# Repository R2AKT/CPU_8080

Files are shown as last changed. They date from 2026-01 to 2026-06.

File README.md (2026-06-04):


License addendum - https://github.com/R2AKT/CPU_8080/blob/main/Addendum.txt
# CPU_8080
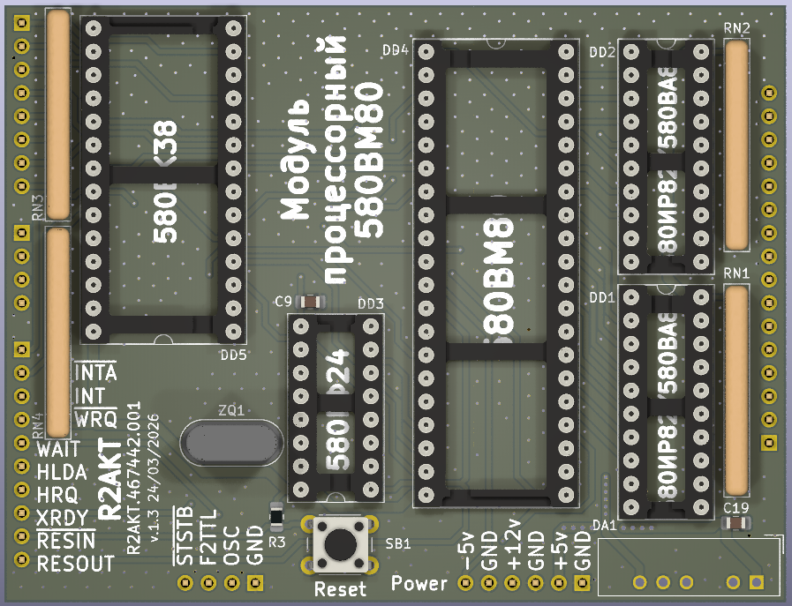
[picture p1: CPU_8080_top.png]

580VM80a (8080a) CPU board.
For Mega-80 (Mega-580) DIY 8-bit micro-computer - https://github.com/R2AKT/Mega-80.

The board includes:
- processor = 580BM80a (8080a);
- clock generator = 580GF24 (8224); 
- data and control bus controller = 580BK28/38 (8228/8238);
- address bus buffer's = 2x580VA86 = (8286).

* There is a project option with the replacement of 580IR82/580V86 with 555AP6 (74LS245).

The board does not contain memory!

Status: tested in conjunction with an 8k linear memory module at a frequency of up to 3 MHz (quartz resonator 27 MHz).

Процессорная плата 580ВМ80а.
Для самодельной 8-битной микро-ЭВМ - https://github.com/R2AKT/Mega-80.

Плата содержит:
- процессор = 580ВМ80а;
- тактовый генератор = 580ГФ24;
- контроллер шины данных и управления = 580ВК28/38;
- буфер шины адреса = 2x580ВА86.

* Имеется вариант проекта с заменой 580ИР82/580ВА86 на 555АП6.

Плата не содержит память!

Статус: проверено совместно с модулем линейной памяти 8к на частоте до 3 МГц (кварцевый резонатор 27 МГц).

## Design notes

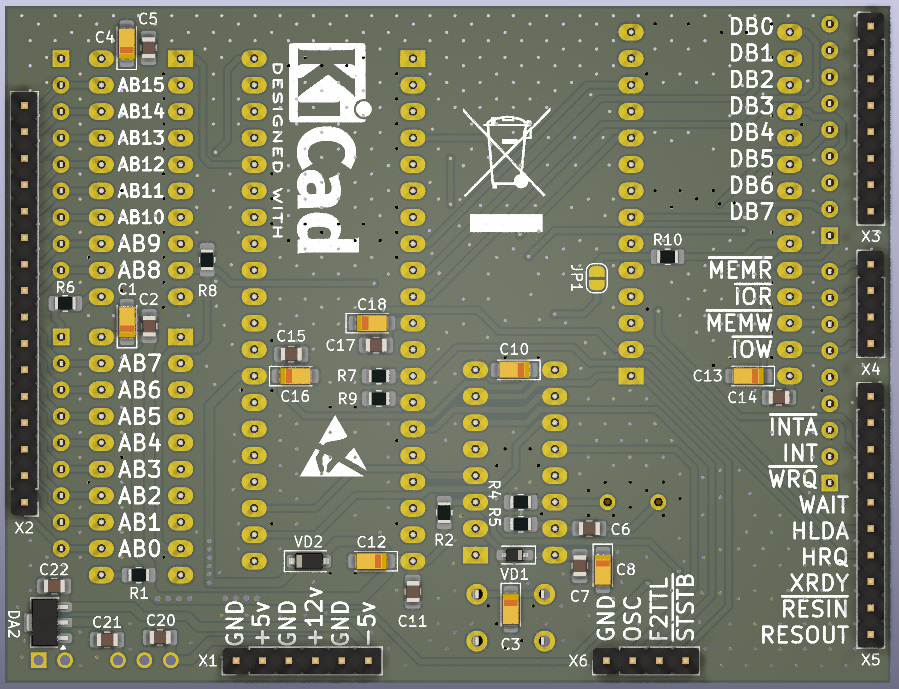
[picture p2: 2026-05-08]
CPU_8080_btn.png

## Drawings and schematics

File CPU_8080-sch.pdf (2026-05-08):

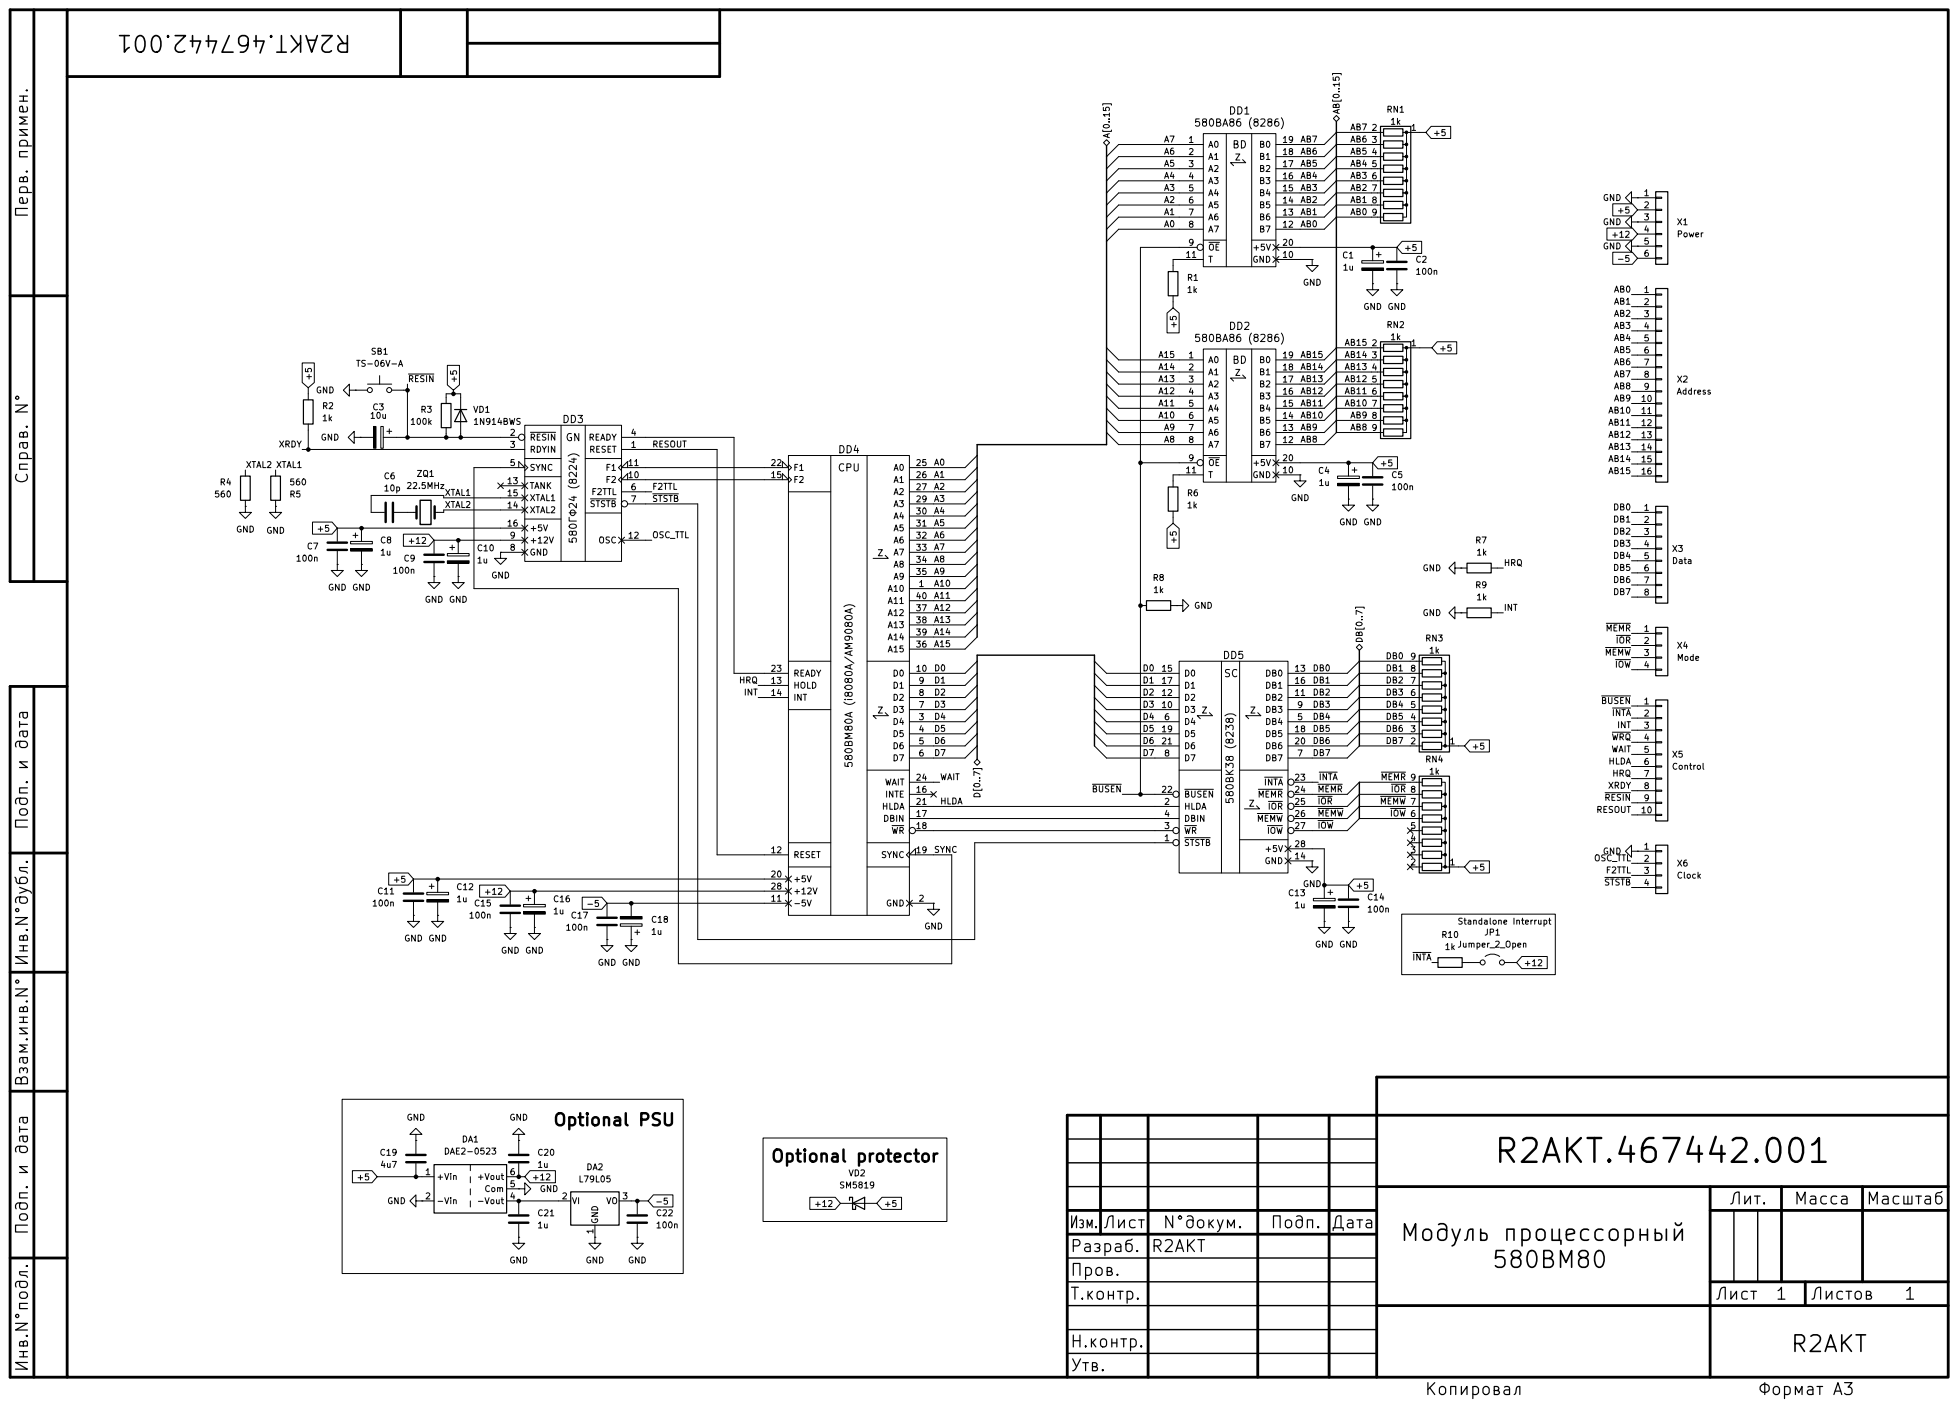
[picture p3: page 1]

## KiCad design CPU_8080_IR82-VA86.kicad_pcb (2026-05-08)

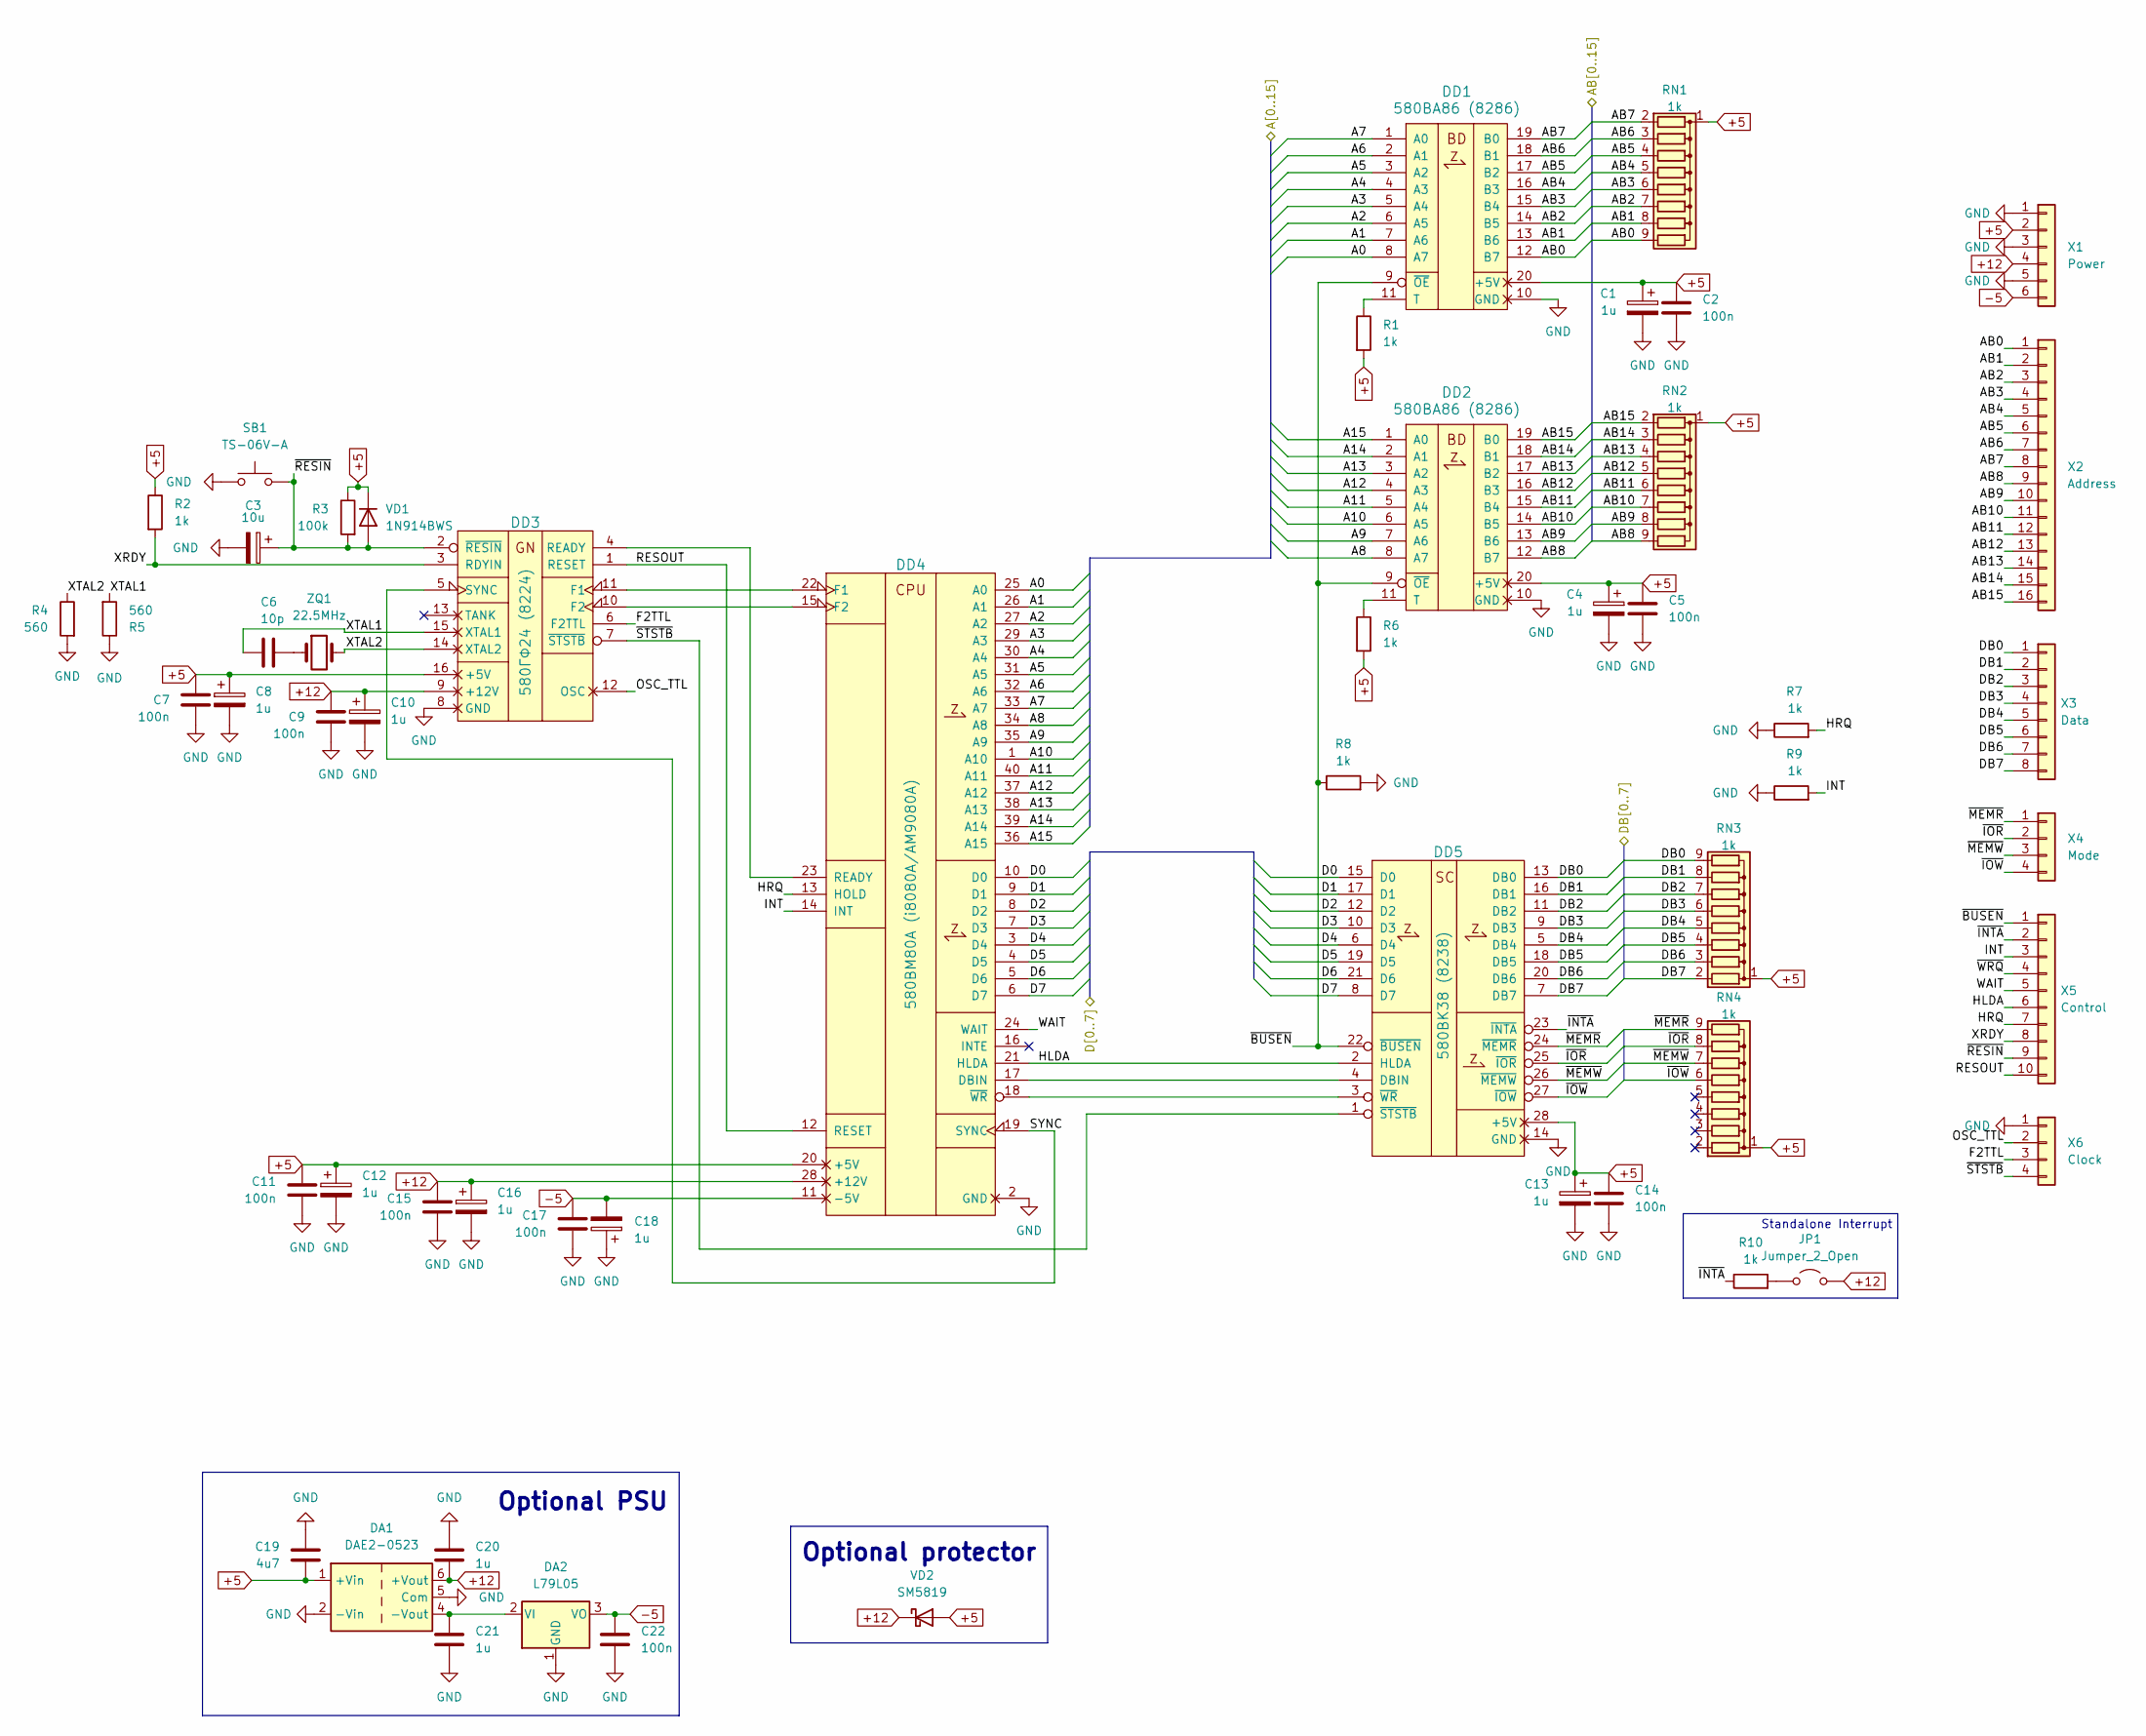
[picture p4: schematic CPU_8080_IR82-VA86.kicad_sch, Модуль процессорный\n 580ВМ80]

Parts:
C1, C4, C8, C10, C12, C13, C16, C18: 1u; CP_EIA-3216-18_Kemet-A_Pad1.58x1.35mm_HandSolder
C2, C5, C7, C9, C11, C14, C15, C17, C22: 100n; C_0805_2012Metric_Pad1.18x1.45mm_HandSolder
C3: 10u; CP_EIA-3216-18_Kemet-A_Pad1.58x1.35mm_HandSolder
C6: 10p; C_0805_2012Metric_Pad1.18x1.45mm_HandSolder
C19: 4u7; C_0805_2012Metric_Pad1.18x1.45mm_HandSolder
C20, C21: 1u; C_0805_2012Metric_Pad1.18x1.45mm_HandSolder
DA1: DAE2-0523; Converter_DCDC_TRACO_TBA1-xxxxE_Dual_THT
DA2: L79L05; SOT-89-3
DD1, DD2: 580ВА86 (8286); DIP-20_W7.62mm_Socket_LongPads
DD3: 580ГФ24 (8224); DIP-16_W7.62mm_Socket_LongPads
DD4: 580ВМ80A (i8080A/AM9080A); DIP-40_W15.24mm_Socket_LongPads
DD5: 580ВК38 (8238); DIP-28_W15.24mm_Socket_LongPads
JP1: Jumper_2_Open; SolderJumper-2_P1.3mm_Open_RoundedPad1.0x1.5mm
R1, R2, R6, R7, R8, R9, R10: 1k; R_0805_2012Metric_Pad1.20x1.40mm_HandSolder
R3: 100k; R_0805_2012Metric_Pad1.20x1.40mm_HandSolder
R4, R5: 560; R_0805_2012Metric_Pad1.20x1.40mm_HandSolder
RN1, RN2, RN3, RN4: 1k; R_Array_SIP9
SB1: TS-06V-A; SW_PUSH_6mm
VD1: 1N914BWS; D_SOD-323_HandSoldering
VD2: SM5819; D_SOD-123
X1: Power; PinHeader_1x06_P2.54mm_Vertical
X2: Address; PinHeader_1x16_P2.54mm_Vertical
X3: Data; PinHeader_1x08_P2.54mm_Vertical
X4: Mode; PinHeader_1x04_P2.54mm_Vertical
X5: Control; PinHeader_1x10_P2.54mm_Vertical
X6: Clock; PinHeader_1x04_P2.54mm_Vertical
ZQ1: 22.5MHz; Crystal_HC49-U_Vertical

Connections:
+5: C1.1, C2.1, C4.1, C5.1, C7.1, C8.1, C11.1, C12.1, C13.1, C14.1, C19.1, DA1.1 (+Vin), DD1.20 (+5V), DD2.20 (+5V), DD3.16 (+5V), DD4.20 (+5V), DD5.28 (+5V), R1.2, R2.1, R3.1, R6.2, RN1.1 (common), RN2.1 (common), RN3.1 (common), RN4.1 (common), VD1.1 (K), VD2.2 (A), X1.2
+12: C9.1, C10.1, C15.1, C16.1, C20.1, DA1.6 (+Vout), DD3.9 (+12V), DD4.28 (+12V), JP1.2 (B), VD2.1 (K), X1.4
-5: C17.1, C18.2, C22.1, DA2.3 (VO), DD4.11 (-5V), X1.6
/A0: DD1.8 (A7), DD4.25 (A0)
/A1: DD1.7 (A6), DD4.26 (A1)
/A2: DD1.6 (A5), DD4.27 (A2)
/A3: DD1.5 (A4), DD4.29 (A3)
/A4: DD1.4 (A3), DD4.30 (A4)
/A5: DD1.3 (A2), DD4.31 (A5)
/A6: DD1.2 (A1), DD4.32 (A6)
/A7: DD1.1 (A0), DD4.33 (A7)
/A8: DD2.8 (A7), DD4.34 (A8)
/A9: DD2.7 (A6), DD4.35 (A9)
/A10: DD2.6 (A5), DD4.1 (A10)
/A11: DD2.5 (A4), DD4.40 (A11)
/A12: DD2.4 (A3), DD4.37 (A12)
/A13: DD2.3 (A2), DD4.38 (A13)
/A14: DD2.2 (A1), DD4.39 (A14)
/A15: DD2.1 (A0), DD4.36 (A15)
/AB0: DD1.12 (B7), RN1.9 (R8), X2.1
/AB1: DD1.13 (B6), RN1.8 (R7), X2.2
/AB2: DD1.14 (B5), RN1.7 (R6), X2.3
/AB3: DD1.15 (B4), RN1.6 (R5), X2.4
/AB4: DD1.16 (B3), RN1.5 (R4), X2.5
/AB5: DD1.17 (B2), RN1.4 (R3), X2.6
/AB6: DD1.18 (B1), RN1.3 (R2), X2.7
/AB7: DD1.19 (B0), RN1.2 (R1), X2.8
/AB8: DD2.12 (B7), RN2.9 (R8), X2.9
/AB9: DD2.13 (B6), RN2.8 (R7), X2.10
/AB10: DD2.14 (B5), RN2.7 (R6), X2.11
/AB11: DD2.15 (B4), RN2.6 (R5), X2.12
/AB12: DD2.16 (B3), RN2.5 (R4), X2.13
/AB13: DD2.17 (B2), RN2.4 (R3), X2.14
/AB14: DD2.18 (B1), RN2.3 (R2), X2.15
/AB15: DD2.19 (B0), RN2.2 (R1), X2.16
/D0: DD4.10 (D0), DD5.15 (D0)
/D1: DD4.9 (D1), DD5.17 (D1)
/D2: DD4.8 (D2), DD5.12 (D2)
/D3: DD4.7 (D3), DD5.10 (D3)
/D4: DD4.3 (D4), DD5.6 (D4)
/D5: DD4.4 (D5), DD5.19 (D5)
/D6: DD4.5 (D6), DD5.21 (D6)
/D7: DD4.6 (D7), DD5.8 (D7)
/DB0: DD5.13 (DB0), RN3.9 (R8), X3.1
/DB1: DD5.16 (DB1), RN3.8 (R7), X3.2
/DB2: DD5.11 (DB2), RN3.7 (R6), X3.3
/DB3: DD5.9 (DB3), RN3.6 (R5), X3.4
/DB4: DD5.5 (DB4), RN3.5 (R4), X3.5
/DB5: DD5.18 (DB5), RN3.4 (R3), X3.6
/DB6: DD5.20 (DB6), RN3.3 (R2), X3.7
/DB7: DD5.7 (DB7), RN3.2 (R1), X3.8
/F2TTL: DD3.6 (F2TTL), X6.3
/HLDA: DD4.21 (HLDA), DD5.2 (HLDA), X5.6
/HRQ: DD4.13 (HOLD), R7.2, X5.7
/INT: DD4.14 (INT), R9.2, X5.3
/OSC_TTL: DD3.12 (OSC), X6.2
/RESOUT: DD3.1 (RESET), DD4.12 (RESET), X5.10
/SYNC: DD3.5 (SYNC), DD4.19 (SYNC)
/WAIT: DD4.24 (WAIT), X5.5
/XRDY: DD3.3 (RDYIN), R2.2, X5.8
/XTAL1: C6.2, DD3.15 (XTAL1), R5.2
/XTAL2: DD3.14 (XTAL2), R4.1, ZQ1.2
/~BUSEN: DD1.9 (~OE), DD2.9 (~OE), DD5.22 (~BUSEN), R8.1, X5.1
/~INTA: DD5.23 (~INTA), R10.1, X5.2
/~IOR: DD5.25 (~IOR), RN4.8 (R7), X4.2
/~IOW: DD5.27 (~IOW), RN4.6 (R5), X4.4
/~MEMR: DD5.24 (~MEMR), RN4.9 (R8), X4.1
/~MEMW: DD5.26 (~MEMW), RN4.7 (R6), X4.3
/~RESIN: C3.1, DD3.2 (~RESIN), R3.2, SB1.2, VD1.2 (A), X5.9
/~STSTB: DD3.7 (~STSTB), DD5.1 (~STSTB), X6.4
/~WRQ: X5.4
GND: C1.2, C2.2, C3.2, C4.2, C5.2, C7.2, C8.2, C9.2, C10.2, C11.2, C12.2, C13.2, C14.2, C15.2, C16.2, C17.2, C18.1, C19.2, C20.2, C21.2, C22.2, DA1.2 (-Vin), DA1.5 (Com), DA2.1 (GND), DD1.10 (GND), DD2.10 (GND), DD3.8 (GND), DD4.2 (GND), DD5.14 (GND), R4.2, R5.1, R7.1, R8.2, R9.1, SB1.1, X1.1, X1.3, X1.5, X6.1
unnamed: C6.1, ZQ1.1
unnamed: C21.1, DA1.4 (-Vout), DA2.2 (VI)
unnamed: DD1.11 (T), R1.1
unnamed: DD2.11 (T), R6.1
unnamed: DD3.11 (F1), DD4.22 (F1)
unnamed: DD3.10 (F2), DD4.15 (F2)
unnamed: DD3.4 (READY), DD4.23 (READY)
unnamed: DD4.17 (DBIN), DD5.4 (DBIN)
unnamed: DD4.18 (~WR), DD5.3 (~WR)
unnamed: JP1.1 (A), R10.2

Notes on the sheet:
Standalone Interrupt
Optional PSU
Optional protector

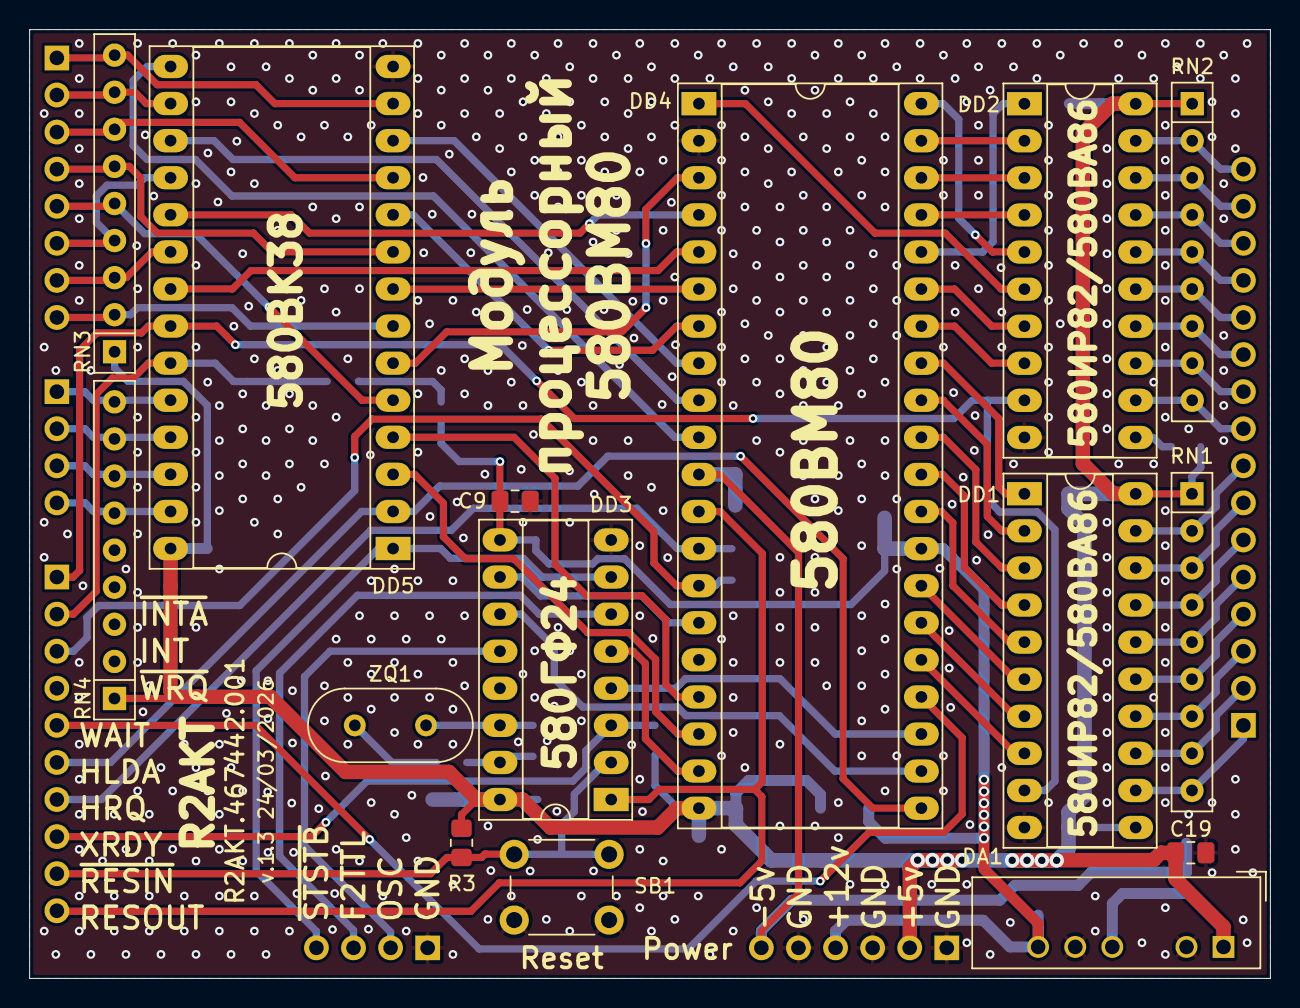
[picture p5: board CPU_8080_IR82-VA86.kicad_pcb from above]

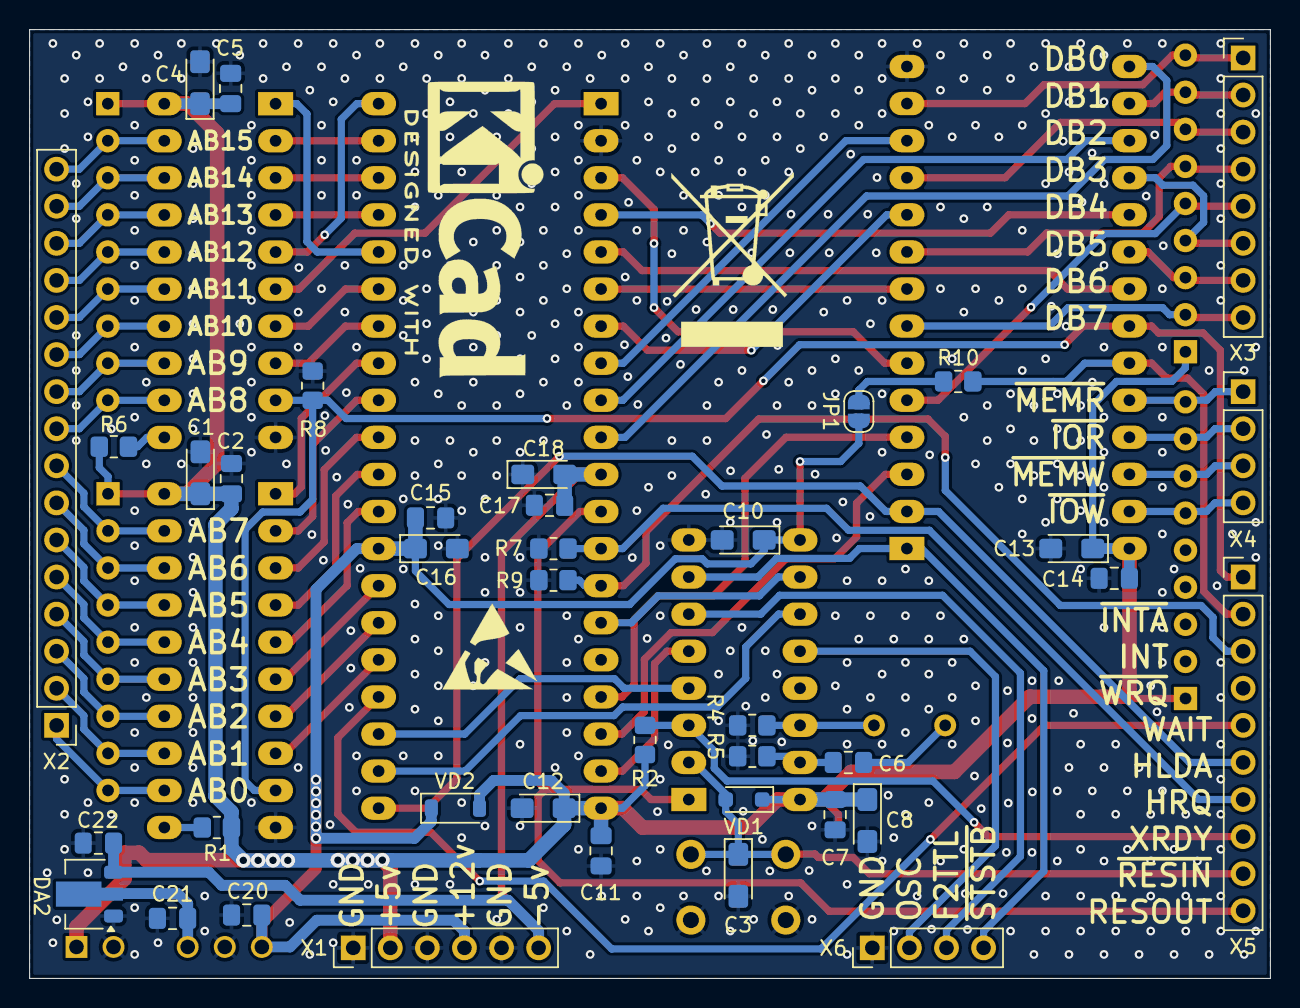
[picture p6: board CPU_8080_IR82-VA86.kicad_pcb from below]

Board: 2 copper layers, 85.0 x 65.0 mm, 54 parts (39 on the bottom side), 81 nets.

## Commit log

2026-01-26 Add files via upload
    Minor fix.
    Незначительные правки.
    [CPU_8080_IR82-VA86.kicad_pcb, CPU_8080_IR82-VA86.kicad_sch]
2026-01-26 Add files via upload
    An option has been added to replace the 580IR82/580VA86 with 555AP6 (74LS245). The version may lag behind the main project.
    Добавлен вариант с заменой 580ИР82/580ВА86 на 555АП6. Версия может отставать от основного проекта.
    [CPU_8080_AP6.kicad_pcb, CPU_8080_AP6.kicad_sch]

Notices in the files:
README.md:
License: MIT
